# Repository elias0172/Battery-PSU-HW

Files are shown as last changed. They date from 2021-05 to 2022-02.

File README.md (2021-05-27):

# Battery-PSU

I bought some batteries from ALDI Sud, they have some cool features:
- They are cheap: you could find one with 20V/5.0A(40V/2.5A) on eBay for about 30€
- Inside the battery pack there are two battery blocks. Each is 20V 2.5A
- The contacts are shown outside B1- B2- T B1+ B2+. 

- You could bride either B1- with B2- and B1+ with B2+ so you will have 20V with 5.0A
  or you could use B1- as GND, bride B2- with B1+ and use B2+ as VCC, you will have 40V with 2.5A.
  
I will use fot this project the higher voltage of max. 42V for a battery operated Bench supply.
In case I use a battery, I also always use an undervoltage detection to securely cut off the battery from the load. Since there is no protection inside the Ferrex batteries, I have to build one. 
There were the next problems with such a high voltage:
Normal DC/DC buck converter doesn´t tolerate voltages above 35V. Also the classic linear regulators 7805 / 78M05 go just up to 35V. Too less.
I bought this module from ebay:
https://www.ebay.de/itm/233171138228
the LM2596HV goes up to 56V. Output is fixed 5V. The accuracy is okey for my purpose.
I desoldered the 5V USB Slot.
Next I designed a PCB with KiCAD that contains just a simple voltage divider, a MCU and a MOS-FET.
https://www.reichelt.de/mosfet-n-ch-55v-30a-68w-to-220ab-irlz-34n-p41777.html
Speaking of MOS-FET: I used the IRLZ34N from Infineon 55V, 30A. 
Later I designed a enclosure in Fusion360 with a Battery Slot, two banana sockets, a fuse and a switch.
The inserted module is a simple DPS5005 from ebay.
https://www.ebay.de/itm/274590698321?var=574812163510
The final PCB result is looking as following:
HV_UV
The final power supply looks like this:


To scew the two parts together, I used four Ruthex M3 Inserts.
https://rb.gy/0ddei3
There are simple 6.3mm faston clamps with angled soldering points. They are made for pcb mount


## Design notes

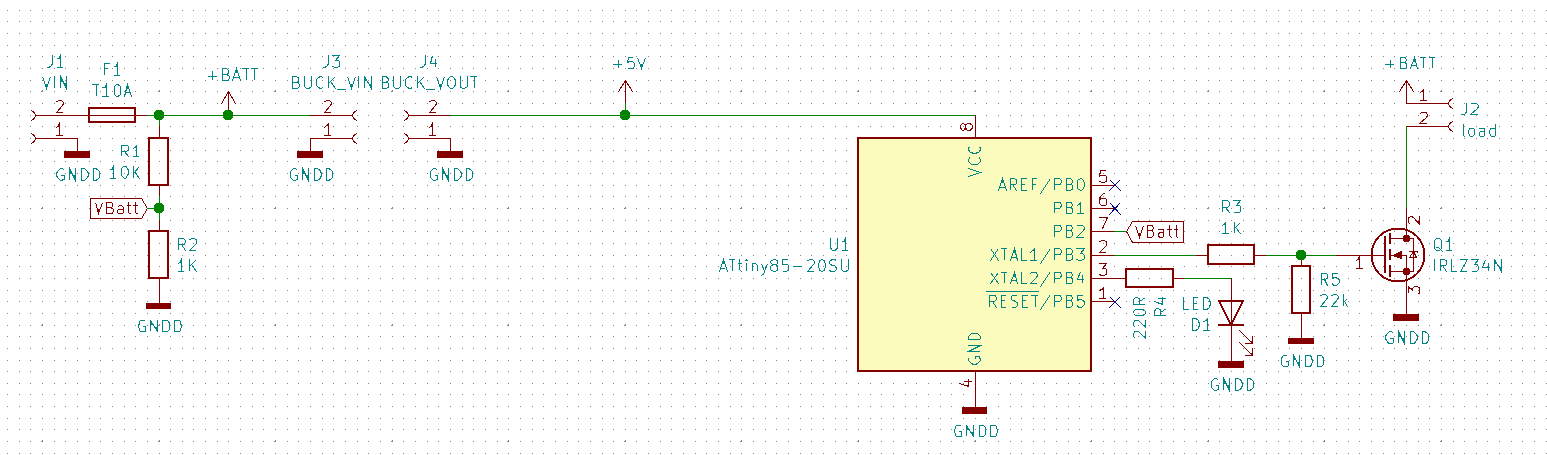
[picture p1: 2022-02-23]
Schematic.png

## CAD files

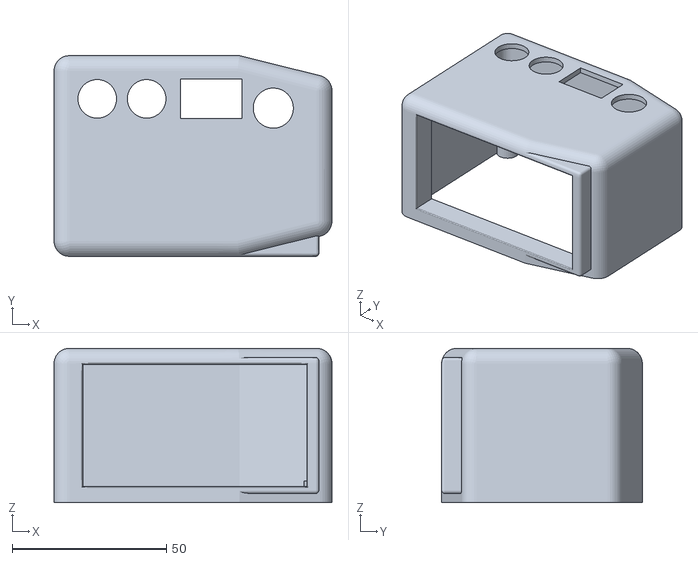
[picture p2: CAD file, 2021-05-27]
3D/Gehäuse.stl
90.0 x 65.0 x 50.0

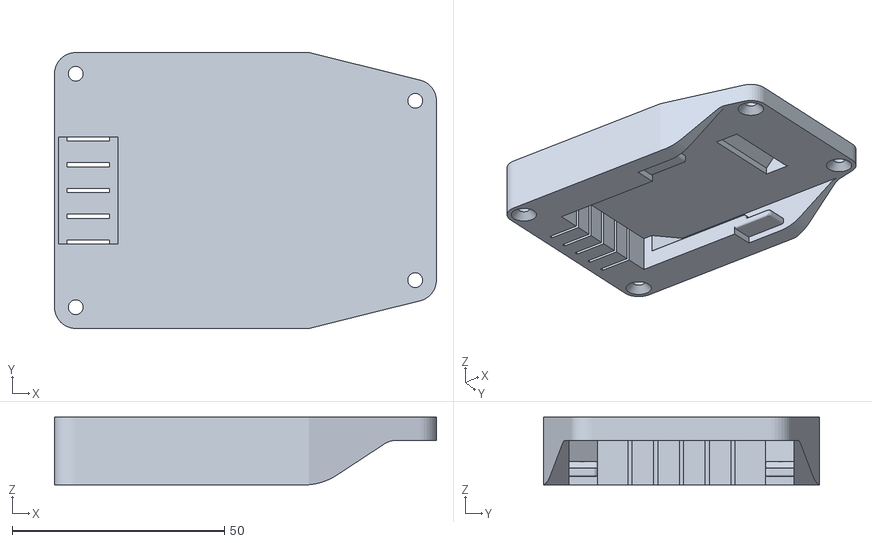
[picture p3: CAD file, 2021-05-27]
3D/Ferrex Akkutray.stl
90.0 x 65.0 x 16.0

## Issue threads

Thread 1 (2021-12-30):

Connect contacts

anno73, 2021-12-30:
Hi!

Interesting concept! Would you mind adding a photo of the inside where one can see the faston connectors connecting to the wires please?

Thanx a lot!

elias0172, 2022-01-08:
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

Hi, thank you!
Unfortunately I covered the faston connectors with hot glue, nevertheless I opened pandora's box and took some photos. I just soldered wires to the pins which goes normally through the pcb.
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

![Uploading t2{b3c8192} (6f754da7-1909-4a22-8a29-cab4a7073e9e id=0x7f0a039e) …]()

Closed 2022-01-08.

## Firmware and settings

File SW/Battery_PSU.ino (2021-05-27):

/*  C 2021 Elias Klimsch
 *  MCU: ATTINY85 */

#include <SoftwareSerial.h>
SoftwareSerial mySerial(0, 1); //RX TX

int transistor = 3;
int led = 4;
int voltage = A1;
float R1 = 10000; //Value from Resistor to VCC in Ohm
float R2 = 1000; //Value from Resistor to GND in Ohm
float VCC_MCU = 5.0; //Supply voltage of µC in Volts
int ADC_Res = 1023; //ADC Resolution in values minus 1
int cells = 10; //Quantity of cells in Series
float threshold = 3.0; //Minimun Voltage per cell
bool state = 1;

void setup()
{
  pinMode(voltage, INPUT);
  pinMode(transistor, OUTPUT);
  pinMode(led, OUTPUT);
  mySerial.begin(4800);
  delay(5000);
}

void loop()
{
  delay(300);
  float act_voltage = ((analogRead(voltage) * (VCC_MCU / ADC_Res)) / (R2 / (R1 + R2))); //Voltage conversion
  mySerial.println(act_voltage);
  if (act_voltage < (cells * threshold)) //calculating threshold voltage
  {
    state = 0;
  }
  mySerial.println(state);
  switch (state)
  {
    case 0: //Lockout
      digitalWrite(transistor, LOW);
      digitalWrite(led, HIGH);
      break;
    case 1: // O.K.
      digitalWrite(transistor, HIGH);
      digitalWrite(led, LOW);
      break;
    default:
      break;
  }
}

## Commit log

2021-05-27 Create PCB
2021-05-27 Added Folder Gerber for manufacturing
    [HV_UV_detect-F_Paste.gbr]
2022-02-23 Provided additional schematic
    Provided additional schematic for undervoltage detection pcb
